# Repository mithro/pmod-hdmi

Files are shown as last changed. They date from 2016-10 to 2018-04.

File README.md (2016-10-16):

# pmod-hdmi-tx

HDMI transmitter based around a PTN3363.

## License

The board template for KiCad is licensed under a Creative Commons
Attribution 4.0 International License.

You should have received a copy of the license along with this
work.  If not, see <http://creativecommons.org/licenses/by/4.0/>.



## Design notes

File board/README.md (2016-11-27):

# Length Matching

 * HDMI_PMOD2CAP
  - 0.4872" (12.37488 mm)
  - 10mil intra pair
  - 1mil inter pair

 * HDMI_CAP2IC
  - 10mil intra pair
  - 1mil inter pair

 * HDMI_I22PORT
  - 15mil intra pair
  - 1mil inter pair

# Board Manufacturing

 *  5mil (0.127mm) trace width
 *  5mil (0.127mm) trace clearance

 * 12 mil (0.3048mm) drill size
 *  6 mil (0.1524mm) annular ring
 * 24 mil (0.6096mm) via size (6mil+12mil+6mil)

 *  6 mil (0.1524) silkscreen width

This can be meet by;
 * [Hackvana by requesting the 5mil option](https://docs.google.com/document/d/1p6FH25ltGpzJQ5_8fbflDukqEKghiEcpuhJpngth2Is/edit)
 * [OHS Park's Four Layer Boards](http://docs.oshpark.com/services/)

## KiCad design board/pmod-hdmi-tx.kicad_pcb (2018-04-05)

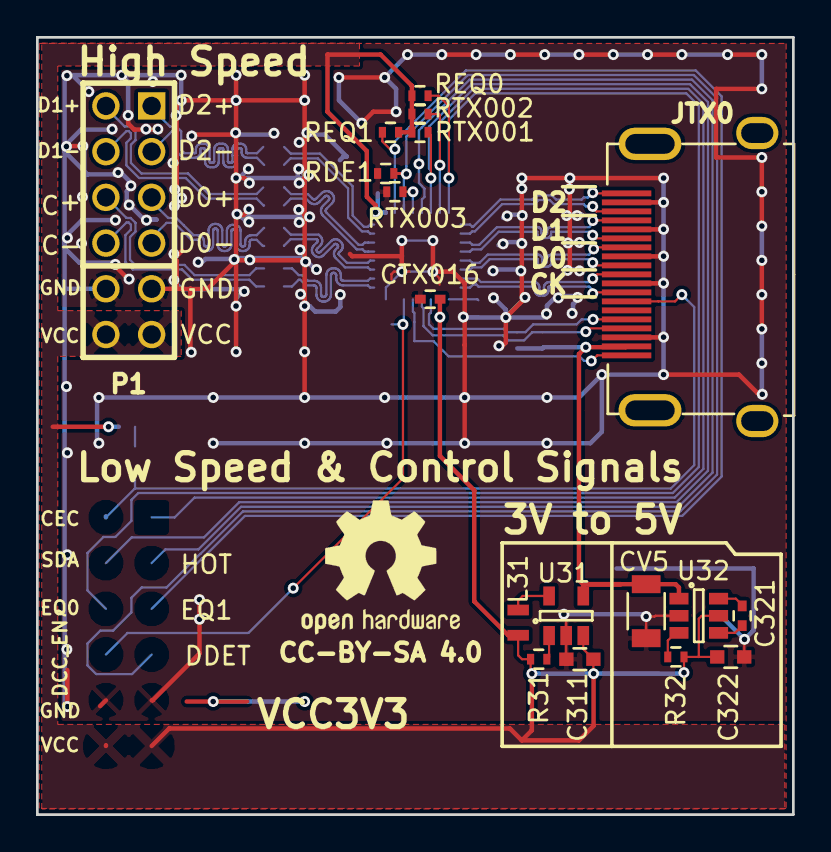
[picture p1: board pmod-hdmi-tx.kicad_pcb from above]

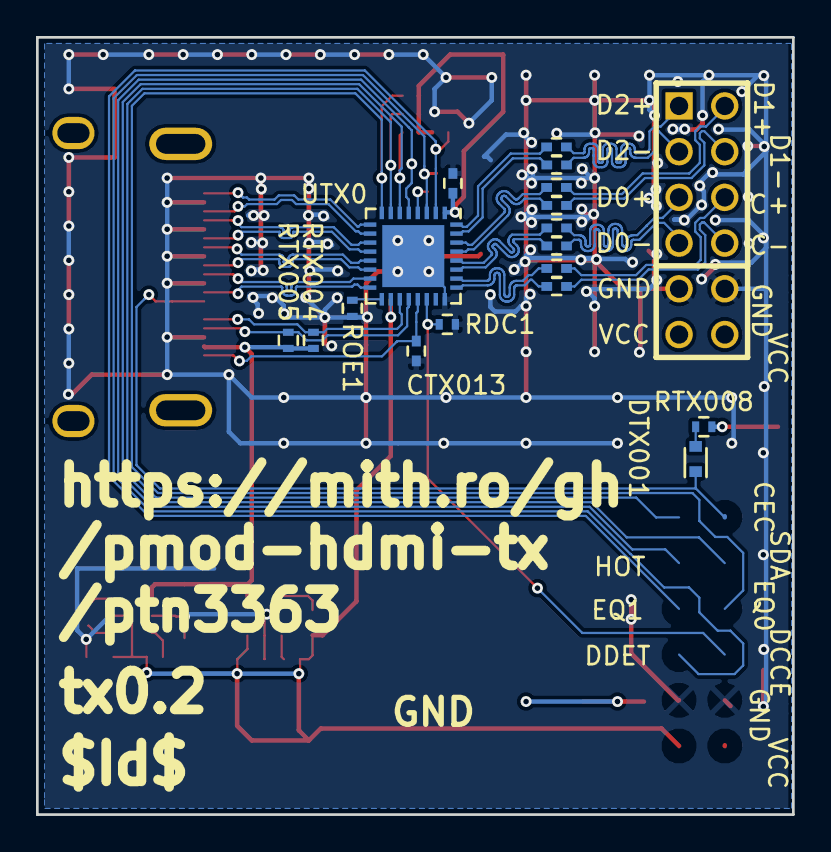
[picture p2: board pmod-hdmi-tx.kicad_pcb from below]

Board: 2 copper layers, 42.0 x 43.2 mm, 35 parts (17 on the bottom side), 38 nets.

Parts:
C311: 4.7uF; C_0603
C321: 220n; C_0402
C322: 2.2uF; C_0603
CTX001, CTX002, CTX003, CTX004, CTX005, CTX006, CTX007, CTX008, CTX016, CTX017: 0.1uF; C_0402
CTX013: 10n; C_0402
CV5: 10uF; C_1206
DTX001: D; SOD-523
JTX0: HDMI_OUT; HDMI_TH
L31: 4.7uH; Neosid_Inductor_SM0603CG
P1: PMOD-Device-x2-Type-XHS-Alt; pmod_pin_array_6x2
R31: 4.7k; R_0402
R32: 10k; R_0402
RDC1: 10k; R_0402
RDE1: 10k; R_0402
REQ0, REQ1: 10k; R_0402
ROE1: 10k; R_0402
RTX001, RTX002, RTX004, RTX005: 2k2; R_0402
RTX003: 12k4; R_0402
RTX008: 27K; R_0402
U31: XC9140; SOT-23-5
U32: REG710-DBV; SOT-23-6
UTX0: PTN3363; QFN-32-1EP_5x5mm_Pitch0.5mm

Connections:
/HDMI TX/HDMIA_TX0_CLK+: CTX001.1, UTX0.26
/HDMI TX/HDMIA_TX0_CLK-: CTX002.1, UTX0.25
/HDMI TX/HDMIA_TX0_D0+: CTX003.1, UTX0.28
/HDMI TX/HDMIA_TX0_D0-: CTX004.1, UTX0.27
/HDMI TX/HDMIA_TX0_D1+: CTX005.1, UTX0.30
/HDMI TX/HDMIA_TX0_D1-: CTX006.1, UTX0.29
/HDMI TX/HDMIA_TX0_D2+: CTX007.1, UTX0.32
/HDMI TX/HDMIA_TX0_D2-: CTX008.1, UTX0.31
/HDMI TX/HDMIP_TX0_CLK+: JTX0.10, UTX0.15
/HDMI TX/HDMIP_TX0_CLK-: JTX0.12, UTX0.16
/HDMI TX/HDMIP_TX0_D0+: JTX0.7, UTX0.13
/HDMI TX/HDMIP_TX0_D0-: JTX0.9, UTX0.14
/HDMI TX/HDMIP_TX0_D1+: JTX0.4, UTX0.11
/HDMI TX/HDMIP_TX0_D1-: JTX0.6, UTX0.12
/HDMI TX/HDMIP_TX0_D2+: JTX0.1, UTX0.9
/HDMI TX/HDMIP_TX0_D2-: JTX0.3, UTX0.10
/HDMI TX/HDMIP_TX0_HOT: CTX013.2, JTX0.19, UTX0.21
/HDMI TX/HDMIP_TX0_SCL: JTX0.15, RTX004.2, UTX0.19
/HDMI TX/HDMIP_TX0_SDA: JTX0.16, RTX005.2, UTX0.20
/HDMI_TX0_CEC: DTX001.1, JTX0.13, P1.7
/HDMI_TX0_DCC_EN: P1.10, RDC1.2, UTX0.22
/HDMI_TX0_DDET: P1.4, RDE1.2, UTX0.3
/HDMI_TX0_EQ0: P1.9, REQ0.2, UTX0.8
/HDMI_TX0_EQ1: P1.3, REQ1.2, UTX0.2
/HDMI_TX0_HOT: P1.2, UTX0.5
/HDMI_TX0_SCL: P1.1, RTX002.2, UTX0.7
/HDMI_TX0_SDA: P1.8, RTX001.2, UTX0.6
/~HDMI_TX0_OE: ROE1.2, UTX0.17
GND: C311.2, C322.2, CTX013.1, CTX016.1, CTX017.1, CV5.2, JTX0.2, JTX0.5, JTX0.8, JTX0.11, JTX0.17, P1.5, P1.11, RDC1.1, RDE1.1, ROE1.1, RTX003.2, U31.2, U32.2, UTX0.24, UTX0.33
unnamed: C321.1, U32.6
unnamed: C321.2, U32.4
unnamed: DTX001.2, RTX008.2
unnamed: L31.2, U31.5
unnamed: R31.1, U31.1
unnamed: R32.1, U32.3
unnamed: RTX003.1, UTX0.4
TX05V0: CV5.1, JTX0.18, RTX004.1, RTX005.1, U31.4, U32.1
VCC3V3: C311.1, C322.1, CTX016.2, CTX017.2, L31.1, P1.6, P1.12, R31.2, R32.2, REQ0.1, REQ1.1, RTX001.1, RTX002.1, RTX008.1, U31.3, U32.5, UTX0.1, UTX0.18

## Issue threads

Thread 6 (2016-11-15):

Collect HDMI output reference examples

mithro, 2016-11-15:
_From @mithro on August 8, 2016 3:15_

_Copied from original issue: mithro/HDMI2USB-pcie-artix7#5_

mithro, 2016-11-15:
# AXIOM Beta Module
 * https://wiki.apertus.org/index.php/Beta_HDMI_Plugin_Module
 * https://wiki.apertus.org/index.php/Axiom_Beta_Plugin_Module_1x_HDMI_v0.8

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

## Specs

 * 1080p60
 * Proven working on AXIOM with a Zynq chip
 * Allows usage on any LVDS bank voltage
 * Uses an [`NXP Semiconductors PTN3363`](http://www.nxp.com/documents/data_sheet/PTN3363.pdf)
 * Provides equalization / amplification
 * Unidirectional - Output only

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

mithro, 2016-11-15:
# Zybo Bidirectional Design

 * http://store.digilentinc.com/zybo-zynq-7000-arm-fpga-soc-trainer-board/
 * https://reference.digilentinc.com/_media/zybo:zybo_sch.pdf
 * Also at https://github.com/mithro/HDMI2USB-pcie-atrix7/issues/6#issuecomment-238140650

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

## Specs

 * Very low part count
 * Bidirectional
 * Unamplified -- only works with short cables.

mithro, 2016-11-15:
# Nexys Video Outputs

 * http://store.digilentinc.com/nexys-video-artix-7-fpga-trainer-board-for-multimedia-applications/
 * https://reference.digilentinc.com/_media/nexys-video:nexys_video_sch.pdf

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

## Specs

 * Known working at 1080p60 with Hamster's design
 * Uses a TMDS141RHAR

mithro, 2016-11-15:
_From @anoopnumato on August 11, 2016 6:17_

@mithro TMDS141RHAR seems reasonable, low cost.

mithro, 2016-11-15:
@anoopnumato The AXIOM beta is the preferred option.

The PTN3363 is 1.26000 USD from Digikey in signal units and drops rapidly in larger numbers (0.57350 USD in 1k). It provides ESD and equalization up to 3.4 Gbit/s (well above our range).

The PTN3363 should also be usable at both the input and output designs. The AXIOM people have verified the PTN3363 for 1080p60 output on an Artix-7.

mithro, 2016-11-15:
_From @anoopnumato on August 11, 2016 6:36_

@mithro This one looks great. So the availability is ok, feature wise this is better than TMDS141RHAR. So can we conclude to go with this option?

mithro, 2016-11-15:
@anoopnumato I need to verify using the PTN3363 for HDMI Input before we conclude.

mithro, 2016-11-15:
_From @rohit-numato on August 11, 2016 7:3_

@mithro @anoopnumato TMDS141RHAR seems to be usable for HDMI Input also...Page 1 itself of datasheet has an application diagram where it is used inside a TV for HDMI Rx http://www.ti.com/lit/ds/symlink/tmds141.pdf

mithro, 2016-11-15:
_From @rohit-numato on August 11, 2016 7:6_

@mithro Anoop seems to prefer going with Nexys Video's design for HDMI _Input_

mithro, 2016-11-15:
For HDMI output, we are going to use the [AXIOM Beta Module](https://github.com/mithro/HDMI2USB-pcie-artix7/issues/5#issuecomment-238133468)

See https://github.com/mithro/HDMI2USB-pcie-artix7/blob/master/board/templates/hdmi_TXn.pro

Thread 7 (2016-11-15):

Collect HDMI input reference examples

mithro, 2016-11-15:
_From @mithro on August 8, 2016 3:23_

_Copied from original issue: mithro/HDMI2USB-pcie-artix7#6_

mithro, 2016-11-15:
# Nexys Video HDMI Input

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

## Specs

 * Uses a AD8195ACPZ
 * Known working with Hamster's design at 1080p60

mithro, 2016-11-15:
# Zybo Bidirectional Design

 * http://store.digilentinc.com/zybo-zynq-7000-arm-fpga-soc-trainer-board/
 * https://reference.digilentinc.com/_media/zybo:zybo_sch.pdf
 * Also in https://github.com/mithro/HDMI2USB-pcie-atrix7/issues/5#issuecomment-238133722

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

## Specs

 * Very low part count
 * Bidirectional
 * Unamplified -- only works with short cables.

mithro, 2016-11-15:
# AD8195 reference example

 * [Found in datasheet](http://www.analog.com/media/en/technical-documentation/data-sheets/AD8195.pdf)

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

mithro, 2016-11-15:
For HDMI input, we are going to use the [AD8195 version / Nexys Video HDMI Input](https://github.com/mithro/HDMI2USB-pcie-artix7/issues/6#issuecomment-238134115)

See https://github.com/mithro/HDMI2USB-pcie-artix7/blob/master/board/templates/hdmi_RXn.pro

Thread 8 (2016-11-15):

Figure out the routing of the HDMI TX PTN3363 design

mithro, 2016-11-15:
_From @mithro on October 12, 2016 3:31_

What the AXIOM people do;
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

mithro, 2016-11-28:
This has been done in the tx branch (https://github.com/mithro/pmod-hdmi/tree/tx) see http://gerblook.org/pcb/BEPw4wtpiyTBWBTd8SWV2H#back

mithro, 2016-11-28:
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

Closed 2016-11-28.

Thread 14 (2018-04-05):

Design boards as 4 layer boards.

esden, 2018-04-05:
For high speed boards and good signal integrity the boards should be designed as 4 layer boards. Two layer is saving money in the wrong place. :D

mithro, 2018-04-06:
@esden - Do you have any reason to believe there are signal integrity problems / issues?

mithro, 2018-04-06:
Lets worry about it when we start seeing problems :-)

Closed 2018-04-06.

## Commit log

2016-10-16 Adding XC9140 3V3 to 5V voltage booster.
2016-10-16 Adding schematic.
    [pmod-hdmi-tx.kicad_pcb, pmod-hdmi-tx.sch]
2016-10-16 Adding HDMI input from template.
    [hdmi_TX0.sch]
2016-10-16 Updating from template.
    [hdmi_TX0.sch]
2016-10-16 Update from template.
    [hdmi_TX0.sch]
2016-10-16 Mostly working schematic.
    [pmod-hdmi-tx.sch]
2016-10-16 Annotate schematic.
    [pmod-hdmi-tx.sch]
2016-10-16 Adding footprints.
    [pmod-hdmi-tx.sch]
2016-10-16 Assigning footprints.
    [pmod-hdmi-tx.sch]
2016-10-16 Update from tempaltes.
    [hdmi_TX0.sch]
2016-10-16 Setting up schematic.
    [hdmi_TX0.sch, pmod-hdmi-tx.kicad_pcb]
2016-10-16 Update from the template.
    [hdmi_TX0.sch]
2016-10-16 Updating the PCB a little.
    [hdmi_TX0.sch, pmod-hdmi-tx.kicad_pcb]
2016-10-27 First version from Phyllis.
    [pmod-hdmi-tx.kicad_pcb]
2016-11-03 Second version from Phyllis.
    [pmod-hdmi-tx.kicad_pcb]
2016-11-10 Update from templates + s/HPD/HOT/ + s/HPA/HOT/
    [hdmi_TX0.sch, pmod-hdmi-tx.kicad_pcb, pmod-hdmi-tx.sch]
2016-11-10 Update from templates.
    [hdmi_TX0.sch]
2016-11-10 Changing how the high speed signals are routed.
    [hdmi_TX0.sch, pmod-hdmi-tx.sch]
2016-11-10 Reorganising the high speed signals.
    [hdmi_TX0.sch, pmod-hdmi-tx.kicad_pcb, pmod-hdmi-tx.sch]
2016-11-10 Fixing the PCB now.
    [pmod-hdmi-tx.kicad_pcb]
2016-11-19 Working on making the high speed lines better.
    [hdmi_TX0.sch, pmod-hdmi-tx.kicad_pcb]
2016-11-19 Reworking stuff.
    [pmod-hdmi-tx.kicad_pcb, pmod-hdmi-tx.sch]
2016-11-27 Starting to get length matching right...
    [pmod-hdmi-tx.kicad_pcb]
2016-11-27 First group matches length.
    [pmod-hdmi-tx.kicad_pcb]
2016-11-27 Lots of small changes...
    [pmod-hdmi-tx.kicad_pcb]
2016-11-27 Everything matches.
    [pmod-hdmi-tx.kicad_pcb]
2016-11-27 Fixing silkscreen.
    [pmod-hdmi-tx.kicad_pcb]
2016-11-27 Small fixes.
    [pmod-hdmi-tx.kicad_pcb]
2016-11-27 Fiddling with the silkscreen.
    [pmod-hdmi-tx.kicad_pcb]
2016-11-27 Tweaking embedded version.
    [pmod-hdmi-tx.kicad_pcb]
2016-11-27 Tweaking a track.
    [pmod-hdmi-tx.kicad_pcb]
2017-07-15 Adding GND/VCC open area.
    [pmod-hdmi-tx.kicad_pcb]
2017-07-15 Fiddling with the silkscreen more.
    [pmod-hdmi-tx.kicad_pcb]
2017-07-15 Fixing the high speed labels.
    [pmod-hdmi-tx.kicad_pcb]
2017-07-15 Bumping version to tx0.1
    [pmod-hdmi-tx-CuBottom.gbl, pmod-hdmi-tx-CuTop.gtl, pmod-hdmi-tx-EdgeCuts.gm1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]
2017-07-27 Fixing the via sizes.
    [pmod-hdmi-tx.kicad_pcb]
2017-07-27 Setting clearance correctly.
    [pmod-hdmi-tx.kicad_pcb]
2017-07-27 Fixing the via DRC violations.
    [pmod-hdmi-tx.kicad_pcb]
2017-07-27 Clearance of 0.1269mm
    [pmod-hdmi-tx.kicad_pcb]
2017-07-28 More fixes.
    [pmod-hdmi-tx.kicad_pcb]
2018-04-05 A bunch of cleanup, see detailed comment below.
    * Reorganized value labels for a better manual placement plan.
    * Replaced manually created dimensions using KiCad dimension object.
    * Removed dimensions that were not anchored to anything obviously
    useful. I assume they are cutandpasta remains.
    * Removed floating items on the Cmts.User layer.
    * Fab notes merged into a single object. There is no need to write the
    text in multiple separate strings and arrange them manually, even if
    it is autogenerated.
    [pmod-hdmi-tx.kicad_pcb]
2018-04-05 Value position adjustment on bottom layer for placement plan.
    [pmod-hdmi-tx.kicad_pcb]
2018-04-05 Adjusted value positions for top side manual placement plan.
    [pmod-hdmi-tx.kicad_pcb]

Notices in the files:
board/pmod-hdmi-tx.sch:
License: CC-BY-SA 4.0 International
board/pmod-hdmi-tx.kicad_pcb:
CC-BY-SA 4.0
